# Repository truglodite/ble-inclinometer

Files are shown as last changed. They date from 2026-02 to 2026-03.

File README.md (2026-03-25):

# ble-inclinometer

### Measure pitch and throw angles on RC aircraft and helis, using the Xiao NRF52840 Sense.

## Features:
* Extremely Small and lightweight sensor form factor vs commercial inclinometers; won't spoil measurements on delicate/flexible surfaces with weak servos
* Very simple stand alone 1s battery only option works with Bluetooth LE using the "NRF Connect Mobile" app (iOS and Andriod)
* Optional OLED display and tare button, for convenient use without a phone (SSD1306)
* Works on surfaces at various angles (ailerons, vee tails, heli blades, etc)
* Sends accurate sub-degree roll and pitch angles ~1 per second, using a running average and floating point math with IMU optimizations
* Displays battery volts (the Xiao has a built in USB powered 1s lithium battery manager, with 50mA and 100mA charge options)
* Simplified PlatformIO flashing with open source libraries included
* LED status indicators (Blue = BLE connected, Green flash = Data updated, Red flash = Taring)
* 3D printable surface clip STL and OLED+button+battery enclosure files included

*Minimal assembly for BLE use, with just a 1s lipo connected to the XIAO*
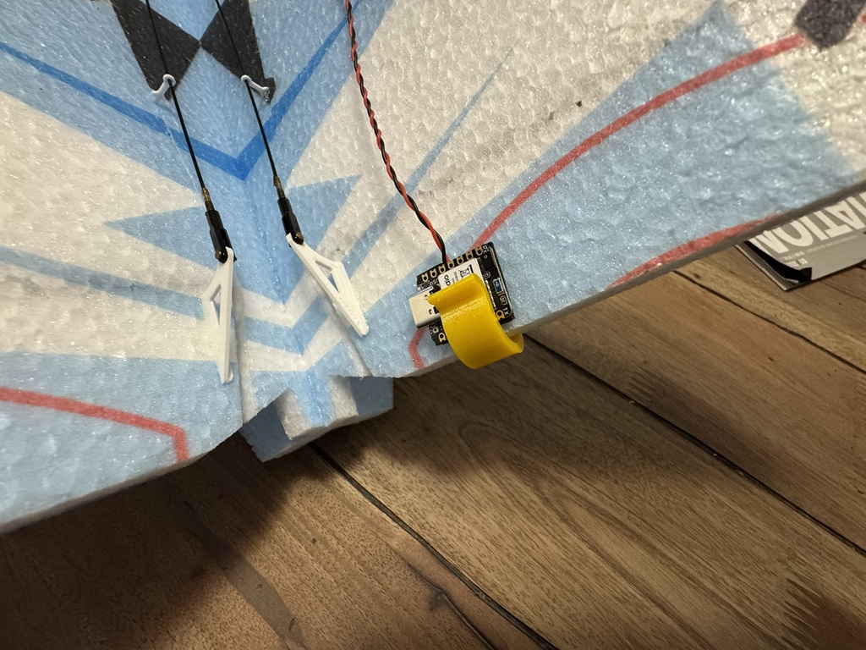
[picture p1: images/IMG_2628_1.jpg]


*Full featured assembly including OLED and tare button, using the included 3d printable files.*
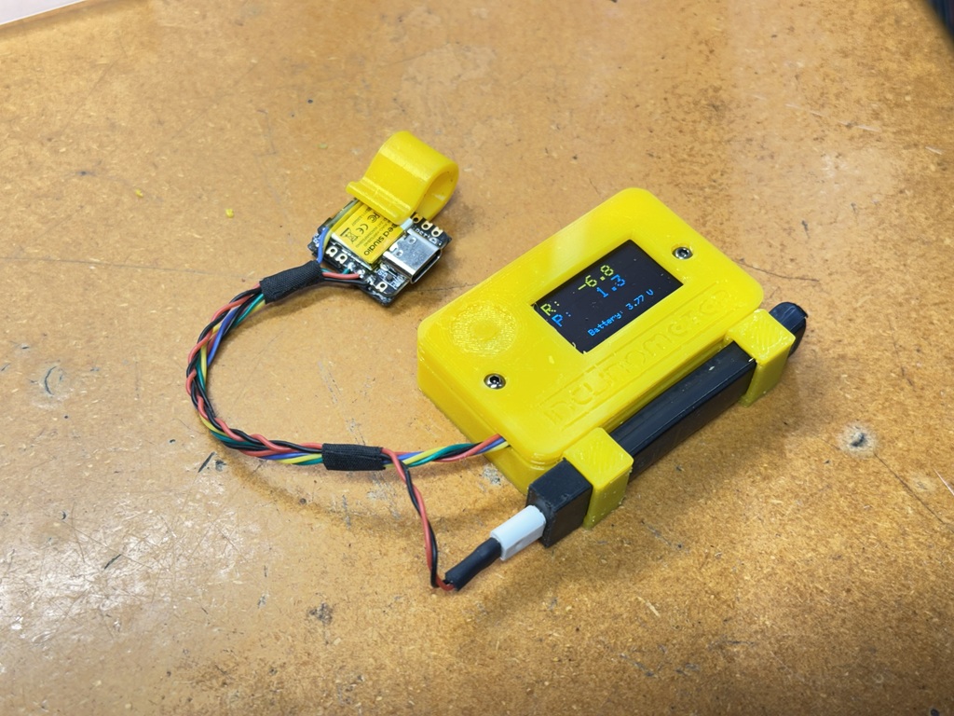
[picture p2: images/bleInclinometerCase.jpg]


## Hardware:
1@ Seeed Studio Xiao NRF52840 Sense board:

https://www.amazon.com/Seeed-Studio-XIAO-nRF52840-Pre-Soldered/dp/B09T94SZ8K/

1@ 1s lithium battery (pretty much any 1s will work):

https://www.amazon.com/flite-300mAh-3-7V-LiPo-Battery/dp/B01FTFZ1ZE/

1@ SSD1306 i2c OLED display (optional):

https://www.amazon.com/HiLetgo-Serial-128X64-Display-Color/dp/B06XRBTBTB/

1@ Momentary N.O. tactile button (optional):

https://www.amazon.com/DAOKI-100Pcs-6x6x5mm-Momentary-Tactile/dp/B07X8T9D2Q/
## Flashing:
#### Flash w/ PlatformIO (recommended):
This option might be easier, since the libraries are included in this repo. I won't go into details of how to use PlatformIO, but it is fairly simple. Download and install vscode, and install the platformIO extension in vscode. Download and unzip this repo to your "Projects" folder, and "Open Folder" in platformio home. Use the right arrow near the bottom to compile and flash.
#### Flash w/ Arduino IDE:
If you don't have the Arduino IDE and Seeed libraries installed on your PC and have a grasp on flashing an Arduino, you should start by reading the software section of this page:

  https://wiki.seeedstudio.com/XIAO_BLE/
  
Note this project will use the "Seeed nRF52 mbed-enabled Boards" since it needs the IMU. You will also have to install the Seeed gyro lib as shown on this page:

  https://wiki.seeedstudio.com/XIAO-BLE-Sense-IMU-Usage/
## Assembly:
Device Pin | Xiao Pin
------------ | ------------
battery +   | Bat+
battery -   | Bat-
OLED VCC    | 3v3
OLED GND    | GND
OLED SDA    | 4
OLED SCL    | 5
button 1a   | 10
button 1b   | gnd

The entire circuit uses very little current. So 30awg or even smaller wire should be adequate. Wire a 1s lithium battery to the BAT+/- pads on the back of the board. The battery can be anything from a rechargeable LR2032 coin cell up to a giant 5000mAh lipo. I recommend using a battery connector, as the battery will drain over time if left connected while not being used. I soldered some 30awg wire to a BT2.0 connector, and use one of my old/tired 1s300 tinywhoop lipos for power. If you are using an OLED and/or a tare button, wire them as shown in the table above.

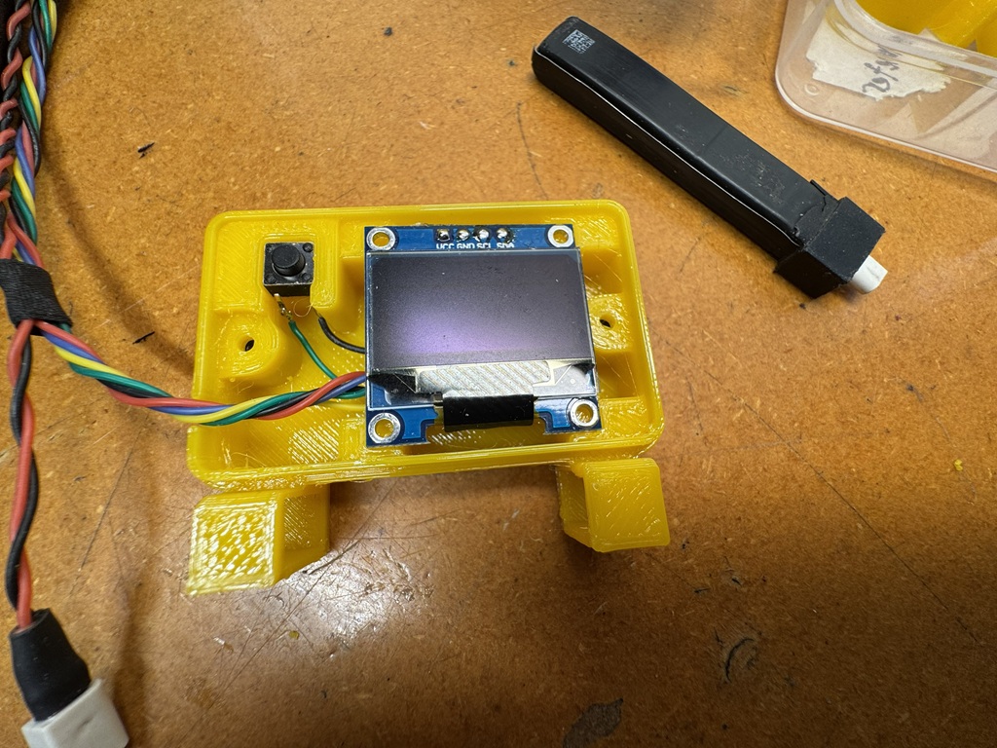
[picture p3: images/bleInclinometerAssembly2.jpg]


Twisted 30awg silicone wire harnesses will have very little effect on movement, even with very weak servos. Avoid using a lot of heatshrink on the harness, or anything else that might make it stiffer. Make the harness long enough so the battery (and OLED+button) can can be comfortably positioned away from the surface without any wire tension during measurments. 6" is usually enough for planes; heli pilots may want a longer harness. Avoid going much longer than ~12" if possible when using an OLED screen; very long wires may result in i2c errors.

It's a good idea to add some protection so the wires don't get damaged over time. I cut pieces of thick/tacky rubber tape (3m 2242) to make a tunnel for the battery wires. This way the board lies in plane with the surface without pinching or rocking on wires. The included clip files are best printed in TPU. They are very gentle on planes, and hold the board securely when 2242 tape is used on the board. Of course you can just use clothespins or whatever else if a 3d printer is not available.

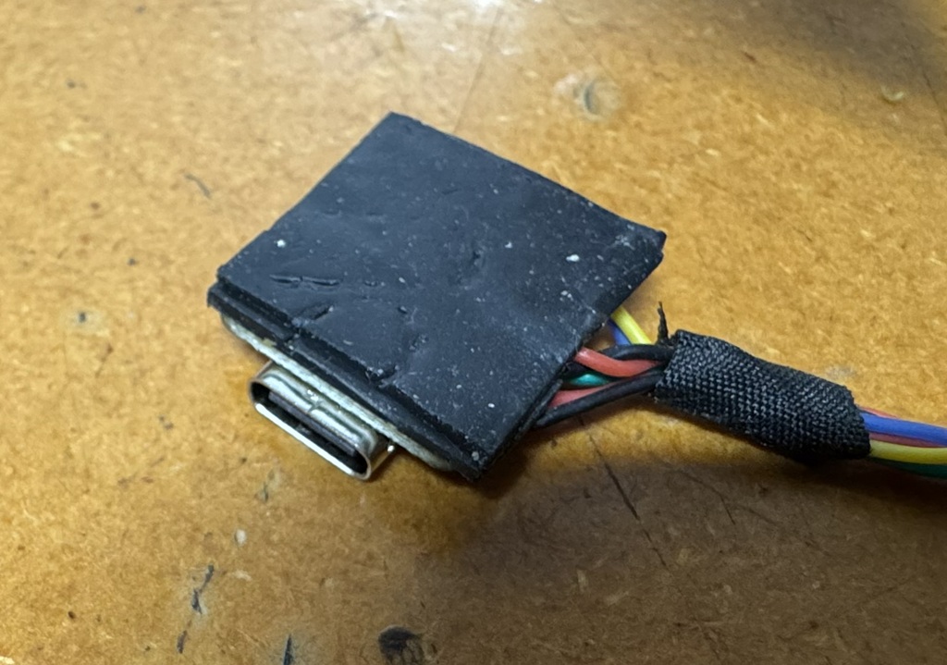
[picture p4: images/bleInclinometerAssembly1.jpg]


If you are using the 3d printable case, TPU is best for durability and to allow easy operation of the 'membrane' tare button. Supports are required for the membrane button and lipo holder areas (not in the text or screw holes). Run the wires through the hole, which has strain relief built in. The button and OLED set in the bottom of the case, and the top is secured with M2 bolts and nuts (the bolt length can vary from 6mm to 17mm; I used M2x7).

## General Use:
Clip the XIAO on the control surface to be measured and procede with measurements as needed. It is best to clip the sensor to your surface such that the roll axis (usb port) is aligned with the axis of rotation (aka "hinge line" or "feathering shaft"). When aligned perfectly, the pitch angle will not change with deflection, and the roll display will perfectly represent travel. Some small changes in pitch angle are fine. However if your measurement requires very high accuracy and you see larger changes in pitch while moving the surface (> +/-5degrees), you may want to try improving the alignment.

Take care the airframe does not move much while measuring (for example keep plane in a cradle so tailwheels/tillers are off the ground). Since only accelerometers are used, measuring yaw is not possible. Therefore you may have to tilt the airframe to measure surfaces that normally rotate about a vertical axis (ie rudders). It isn't necessary to have the surface completely horizontal; within 60 degrees of horizontal is usually good enough to get accurate measurements.

Use the Tare function (via button or BLE) to zero the angles at any position (ie sticks centered after subtrim). Use measurements to setup surface endpoints, control rates, etc.
#### Bluetooth Details:
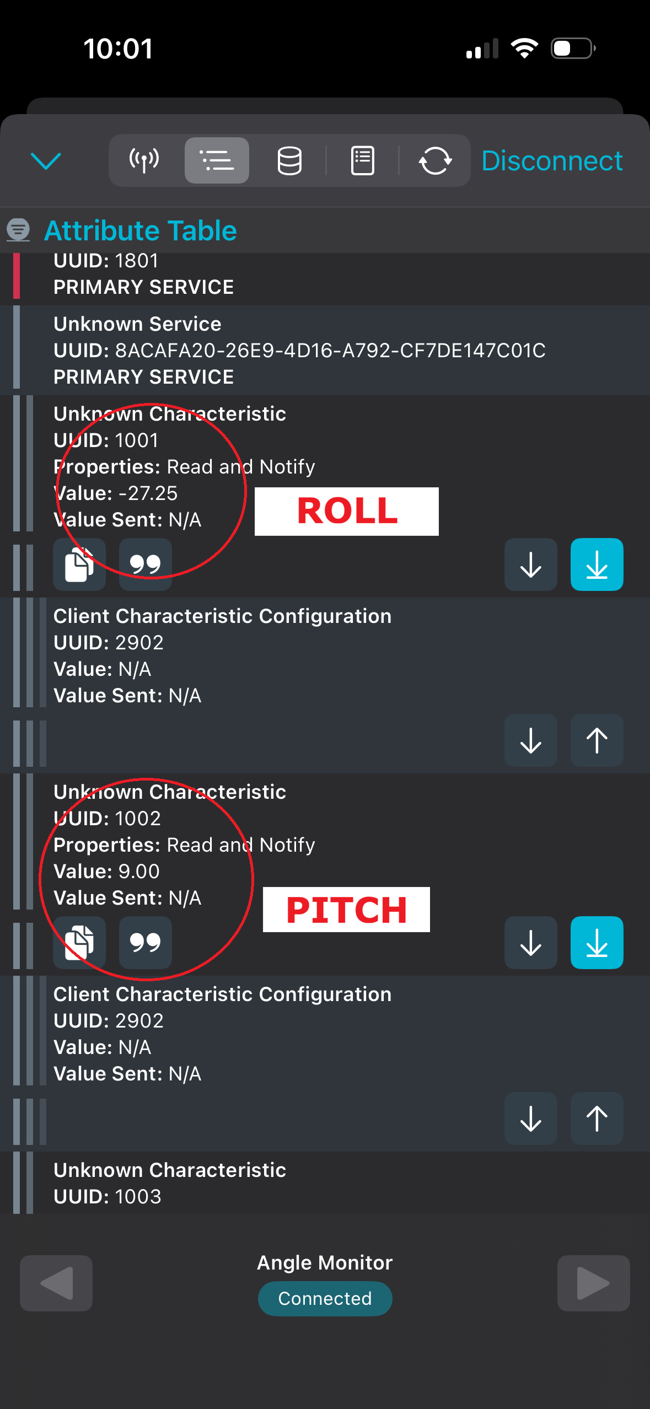
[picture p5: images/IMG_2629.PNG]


UUID | Name | Units
--- | -------- | ---
1001 | Roll axis | degrees
1002 | Pitch axis | degrees
1003 | Tare both axis | send "TRUE"
1004 | Battery Voltage | V

Install the "NRF Connect" app on your phone. When you power up your inclinometer, it will show up in the app as *"Angle Monitor"*. Connect to it, and the characteristics (sensors and controls) will appear in a list. Click the *"down-bar"* arrows on the sensor UUID's (1001, 1002, & 1003) to get continuously updated values. Click the *"quotes"* and select *"UTF-8"*. Now the angles and voltage should display correctly. Tare by clicking the "Up Arrow" on the tare UUID (1003), and send a Boolean "True" (or an UnsignedInt "1").

If you are use an OLED, bluetooth connection info will show on the screen. If you have not enabled "formatOledBig, the bluetooth info line will either show "BT: disconnected" if no phone is connected, or "BT: (MAC address of connected phone)". If you use "formatOledBig", bluetooth info and battery voltage will alternate on the bottom line every ~2.5seconds.

Proper descriptor names are included with all BLE characteristics. Unfortunately NRF Connect (and many similar apps) do not read or make use of them. If there's an app that does, actual sensor names are available in the transmissions.
## Notes:
* The roll is axis is oriented "going in to the USB"
* The pitch axis is oriented "across the width of the USB"
* Use the "chargeCurrent" compile option to select between 50mA and 100mA battery charging current (50mA default)
* "updateDelay" compile option to adjust refresh rate (1sec default, limited by the phone app)
* Compile using the mbed board definition: "Seeed NRF-52 mbed enabled boards\Xiao nRF52840 Sense (No Update)"
* Use the "oledFormatBig" compile option for a larger font. Best for monochrome SSD1306 displays (not so great with Y/B displays)
* Uploaded stl files in 3 sizes: 0mm, 3mm, and 6mm. Print a set with TPU to suit many different surface thicknesses... or just use a clothes pin.
## Project Roadmap:
* ...done?

I'm not a professional programmer, and this project is nothing special. Please use, modify, and/or share the code however you wish. ;)

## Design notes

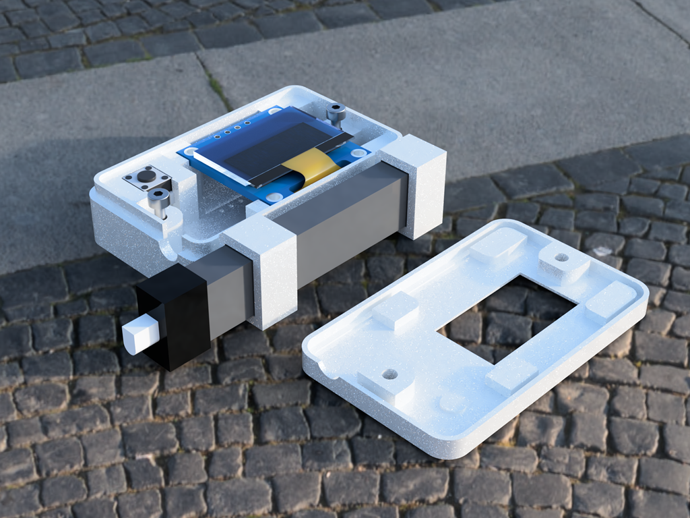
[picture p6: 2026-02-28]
images/bleInclinometerCase3.PNG

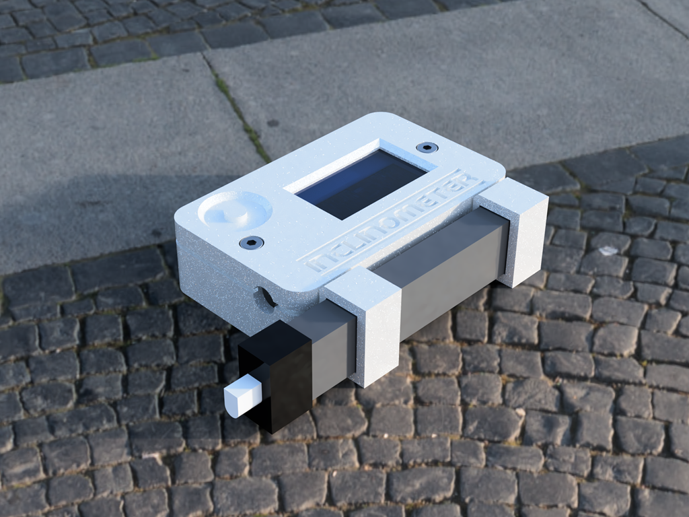
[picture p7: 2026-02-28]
images/bleInclinometerCase1.PNG

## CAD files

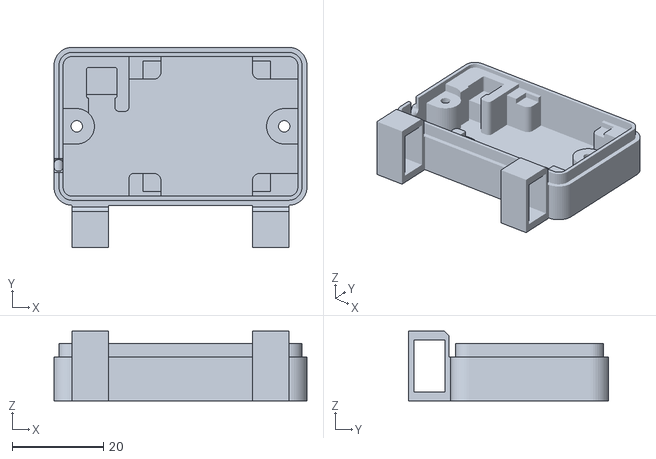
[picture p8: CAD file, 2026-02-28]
models/bleInclinometerCaseBottom.stl
55.6 x 44.0 x 15.3

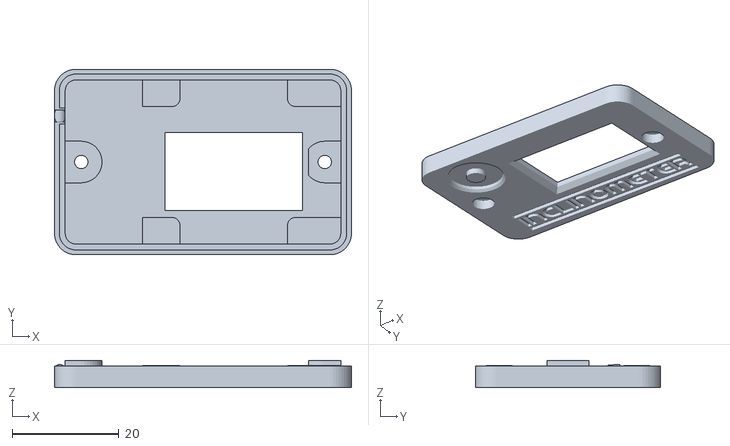
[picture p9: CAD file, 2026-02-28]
models/bleInclinometerCaseTop.stl
55.6 x 34.7 x 5.08

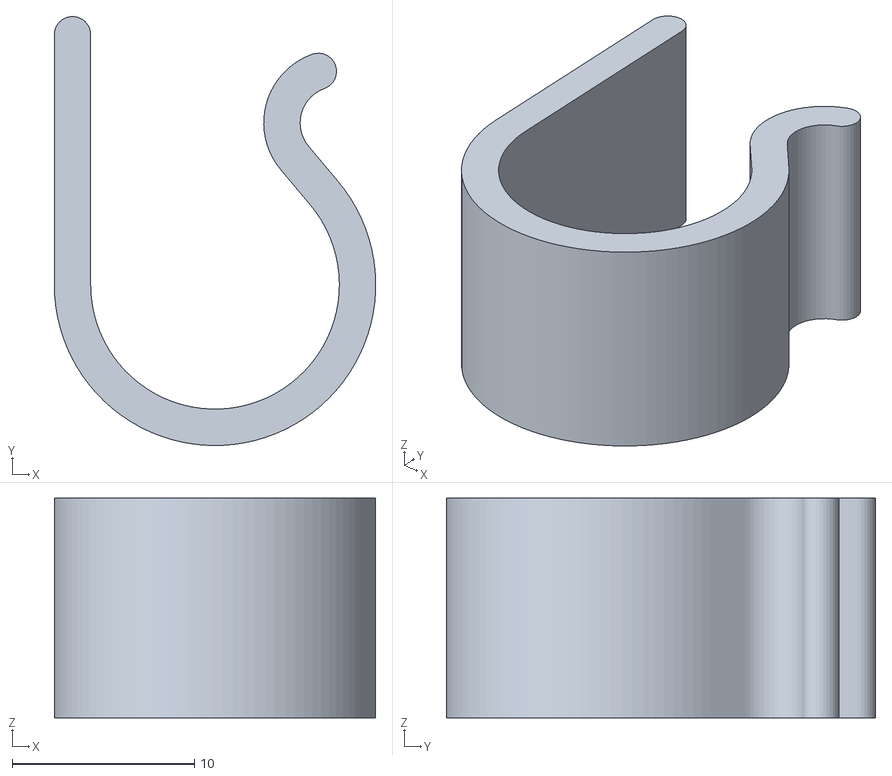
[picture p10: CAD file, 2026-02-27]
models/bleInclinometerClip6mm.stl
17.7 x 23.6 x 12.1

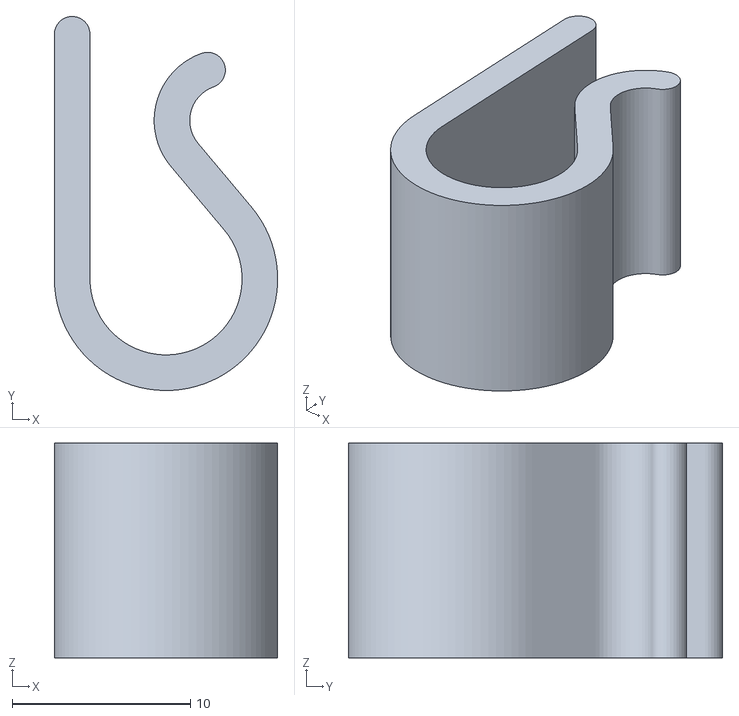
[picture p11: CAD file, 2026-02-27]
models/bleInclinometerClip0mm.stl
12.5 x 21.0 x 12.1

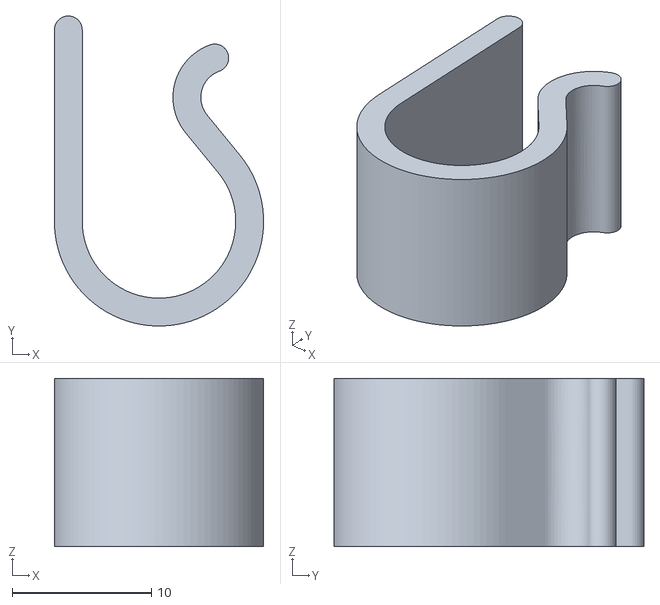
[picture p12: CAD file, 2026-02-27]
models/bleInclinometerClip3mm.stl
15.0 x 22.2 x 12.1

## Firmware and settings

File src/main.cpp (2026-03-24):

// ble-inclinometer
// written by: Truglodite 2/26/26
// The perfect tool for setting rc aircraft control throw, and other angle measurement needs.
// This code is written for the "Xiao NRF52840 Sense" board (use the "mbed" board definition).
// Standalone use with just a battery and a phone app (NRF Connect Mobile, for iOS and Android).
// Optional OLED display can be used for operation without a phone (SSD1306 i2c).
// Optional tare button can be connected for operation without a phone.

// Usage:
// Flash the board, power it on, and connect it to the app.
// Subscribe to the roll (1001) and pitch (1002) sensors ("down/line arrow" buttons).
// Configure the data as "UTF-8" ("quote" buttons).
// To zero both axis, send a true boolean (or 1) to the tare service (1003) (up arrow on sensor w/ long uuid), or push the tare button.
// If using a battery for power via the battery pads, subscribe to the battery service (1004) to read battery volts.
// Roll axis goes into the usb, pitch is across the usb.
// LEDs indicate status: Blue = BLE connected, Green flash = Data updated, Red flash = Taring

//  Wiring:
//  Device Pin | Xiao Pin
//  ------------ | ------------
//  battery +   | Bat+
//  battery -   | Bat-
//  OLED VCC    | 3v3
//  OLED GND    | GND
//  OLED SDA    | 4
//  OLED SCL    | 5
//  button 1a   | 10
//  button 1b   | gnd

// Arduino requires the seeed gyro lib (not the 'duino download): https://github.com/Seeed-Studio/Seeed_Arduino_LSM6DS3

#include <Arduino.h>
#include "ArduinoBLE.h"
#include "LSM6DS3.h"
#include "Wire.h"
#include <nrf52840.h>
#include <nrfx_saadc.h>
#include <AnalogIn.h>
#include <pinDefinitions.h>
#include <avr/dtostrf.h>
#include <Adafruit_SSD1306.h>

// User configuration
#define sampleCount 100 // # of samples between readings
#define tareLEDtime 2000   // msec wait while taring angles (longer than time required to collect sampleCount data points)
#define dataFlash 50   // msec to flash when data is sent
#define chargeCurrent LOW // Built in battery charger: HIGH = 50mA, LOW = 100mA
#define ledColorData LED_GREEN  // LED indicator colors, choose one each (LED_GREEN, LED_RED, LED_BLUE)
#define ledColorBLE LED_BLUE
#define ledColorTare LED_RED
#define tareButtonPin 11  // Pin connected to tare button (11 is IO, 10 is MOSI :P)
//#define oledFormatBig // uncomment for a larger degree display on the OLED (nice for single color screens, not so great with Y/B screens)
#define displayAlternatePeriod 2500 // msec to alternate between info when using oledFormatBig

// END User configuration

#define chargePin P0_13
#define batteryReadPin P0_14
#define batteryAnalogPin P0_31
LSM6DS3 myIMU(I2C_MODE, 0x6A);    //I2C device address 0x6A

// Characteristic UUID's
#define BLE_UUID_ANGLE_MONITOR_SERVICE "8acafa20-26e9-4d16-a792-cf7de147c01c"  // v4 random uuid
#define BLE_UUID_ROLL_DEGREES  "1001"
#define BLE_UUID_PITCH_DEGREES  "1002"
#define BLE_UUID_TARE_SWITCH  "1003"
#define BLE_UUID_BATTERY_VOLTS  "1004"
//#define BLE_UUID_BATTERY_VOLTS  "5726c19a-8a75-5d7a-845d-aadf6734d7e7"  // V5 uuid's
//#define BLE_UUID_ROLL_DEGREES  "a68e1ad6-8c88-56f4-b9d5-792af19cfb19"
//#define BLE_UUID_PITCH_DEGREES  "d9bc177b-1fbe-5724-867a-558e397f2401"
//#define BLE_UUID_TARE_SWITCH  "f7a73029-a679-5de1-8448-ba3d23450f75"

// Bluetooth® Low Energy Battery Service
BLEService angleMonitorService(BLE_UUID_ANGLE_MONITOR_SERVICE);

// Bluetooth® Low Energy Characteristics & Descriptors
BLEStringCharacteristic batteryVolts(BLE_UUID_BATTERY_VOLTS, BLERead | BLENotify, 20);
BLEStringCharacteristic rollDegrees(BLE_UUID_ROLL_DEGREES, BLERead | BLENotify, 20);
BLEStringCharacteristic pitchDegrees(BLE_UUID_PITCH_DEGREES, BLERead | BLENotify, 20);
BLEByteCharacteristic tareChar(BLE_UUID_TARE_SWITCH, BLERead | BLEWrite);

// BLE Descriptors (not read by NRF connect app unfortunately, but here in case some app does)
BLEDescriptor pitchDegreesDescriptor("2901", "Pitch Degrees");
BLEDescriptor rollDegreesDescriptor("2901", "Roll Degrees");
BLEDescriptor batteryVoltsDescriptor("2901", "Batt Volts");
BLEDescriptor tareCharDescriptor("2901", "Tare");

// SSD1306 OLED display parameters
#define SCREEN_WIDTH 128
#define SCREEN_HEIGHT 64
#define OLED_RESET    -1

// I²C pins used by the SSD1306
// Xiao nRF52840 Sense: pin 4 and pin 5
Adafruit_SSD1306 display(SCREEN_WIDTH, SCREEN_HEIGHT, &Wire, OLED_RESET);

float battery = 0.0;  // battery voltage
char batteryBuffer[20]; // printable byte array
float roll = 0;  // roll angle
char rollBuffer[20]; // printable byte array
float pitch = 0;  // pitch angle
char pitchBuffer[20]; // printable byte array
float rollRaw = 0.0;  // raw calculated roll
float pitchRaw = 0.0;  // raw calculated pitch
float accX = 0.0; // accelerator sums
float accY = 0.0;
float accZ = 0.0;
float tareRoll = 0.0;  // raw roll value when tared
float tarePitch = 0.0;  // raw pitch value when tared
long currentMillis = 0; // global timer
long previousData = 0;  // msec since data was sent
long previousTare = 0;  // msec timer for data led flash
long previousDisplay = 0;  // msec timer for data led flash
u_int8_t displayIndex = 0; // display index for alternating displays
bool dataLedFlag = 0;  // flag for data led flash
bool tareFlag = 0;  // flag for tare routine
bool tareLedFlag = 0; // flag for tare led timer
bool centralFlag = 0; // flag if BLE is connected
String centralAddress = "0"; // array to store MAC address of connected BLE device
u_int8_t samples = 0;  // sample count storage

#define SPLASH_HEIGHT   64
#define SPLAST_WIDTH    128

static const unsigned char splashScreen[] = { // Size 128x64 pixels
    0xff, 0xff, 0xff, 0xff, 0xff, 0xff, 0xff, 0xff, 0xff, 0xff, 0xff, 0xff, 0xff, 0xff, 0xff, 0xff,
    0xff, 0xff, 0xff, 0xff, 0xff, 0xff, 0xff, 0xff, 0xff, 0xff, 0xff, 0xff, 0xff, 0xff, 0xff, 0xff,
    0xff, 0xff, 0xff, 0xff, 0xff, 0xff, 0xff, 0xff, 0xff, 0xff, 0xff, 0xff, 0xff, 0xff, 0xff, 0xff,
    0xff, 0xff, 0xff, 0xff, 0xff, 0xff, 0xc0, 0x00, 0x00, 0x1f, 0xff, 0xff, 0xff, 0xff, 0xff, 0xff,
    0xff, 0xff, 0xff, 0xff, 0xff, 0xff, 0xc0, 0x00, 0x00, 0x1f, 0xff, 0xff, 0xff, 0xff, 0xff, 0xff,
    0xff, 0xff, 0xff, 0xff, 0xff, 0xff, 0xff, 0xff, 0xff, 0xff, 0xff, 0xff, 0xff, 0xff, 0xff, 0xff,
    0xff, 0xff, 0xff, 0xff, 0xff, 0xff, 0xff, 0xff, 0xff, 0xff, 0xff, 0xff, 0xff, 0xff, 0xff, 0xff,
    0xff, 0xff, 0xff, 0xff, 0xff, 0xff, 0xe0, 0x13, 0xf8, 0x1f, 0xff, 0xff, 0xff, 0xff, 0xff, 0xff,
    0xff, 0xff, 0xff, 0xff, 0xff, 0xff, 0xe7, 0x93, 0xf1, 0xff, 0xff, 0xff, 0xff, 0xff, 0xff, 0xff,
    0xff, 0xff, 0xff, 0xff, 0xff, 0xff, 0xe7, 0x93, 0xf3, 0xff, 0xff, 0xff, 0xff, 0xff, 0xff, 0xff,
    0xff, 0xff, 0xff, 0xff, 0xff, 0xff, 0xe4, 0x13, 0xf2, 0x1f, 0xff, 0xff, 0xff, 0xff, 0xff, 0xff,
    0xff, 0xff, 0xff, 0xff, 0xff, 0xff, 0xe4, 0x13, 0xf2, 0x3f, 0xff, 0xff, 0xff, 0xff, 0xff, 0xff,
    0xff, 0xff, 0xff, 0xff, 0xff, 0xff, 0xe7, 0x93, 0xf1, 0xff, 0xff, 0xff, 0xff, 0xff, 0xff, 0xff,
    0xff, 0xff, 0xff, 0xff, 0xff, 0xff, 0xe0, 0x10, 0x38, 0x1f, 0xff, 0xff, 0xff, 0xff, 0xff, 0xff,
    0xff, 0xff, 0xff, 0xff, 0xff, 0xff, 0xe0, 0x30, 0x1c, 0x1f, 0xff, 0xff, 0xff, 0xff, 0xff, 0xff,
    0xff, 0xff, 0xff, 0xff, 0xff, 0xff, 0xff, 0xff, 0xff, 0xff, 0xff, 0xff, 0xff, 0xff, 0xff, 0xff,
    0xff, 0xff, 0xff, 0xff, 0xff, 0xff, 0xff, 0xff, 0xff, 0xff, 0xff, 0xff, 0xff, 0xff, 0xff, 0xff,
    0xff, 0xff, 0xff, 0xff, 0xff, 0xff, 0xc0, 0x00, 0x00, 0x0f, 0xff, 0xff, 0xff, 0xff, 0xff, 0xff,
    0xff, 0xff, 0xff, 0xff, 0xff, 0xff, 0xe0, 0x00, 0x00, 0x1f, 0xff, 0xff, 0xff, 0xff, 0xff, 0xff,
    0xff, 0xff, 0xff, 0xff, 0xff, 0xff, 0xff, 0xff, 0xff, 0xff, 0xff, 0xff, 0xff, 0xff, 0xff, 0xff,
    0xff, 0xff, 0xff, 0xff, 0xff, 0xff, 0xff, 0xff, 0xff, 0xff, 0xff, 0xff, 0xff, 0xff, 0xff, 0xff,
    0xff, 0xfc, 0x00, 0x00, 0x00, 0x00, 0x00, 0x00, 0x00, 0x00, 0x00, 0x00, 0x00, 0x00, 0xff, 0xff,
    0xff, 0xfc, 0x00, 0x00, 0x00, 0x00, 0x00, 0x00, 0x00, 0x00, 0x00, 0x00, 0x00, 0x00, 0xff, 0xff,
    0xff, 0xff, 0xff, 0xff, 0xff, 0xff, 0xff, 0xff, 0xff, 0xff, 0xff, 0xff, 0xff, 0xff, 0xff, 0xff,
    0xff, 0xff, 0xff, 0xff, 0xff, 0xff, 0xff, 0xff, 0xff, 0xff, 0xff, 0xff, 0xff, 0xff, 0xff, 0xff,
    0xff, 0xfc, 0xe0, 0xf8, 0x27, 0xce, 0x0f, 0x03, 0xc0, 0x0e, 0x04, 0x03, 0x02, 0x01, 0xff, 0xff,
    0xff, 0xfc, 0xc4, 0x71, 0xe7, 0xcc, 0x46, 0x31, 0x98, 0xcc, 0x7f, 0x1e, 0x3e, 0x31, 0xff, 0xff,
    0xff, 0xfc, 0x9f, 0x27, 0xe7, 0xc9, 0xf2, 0x79, 0x98, 0xcc, 0xff, 0x9e, 0x7e, 0x78, 0xff, 0xff,
    0xff, 0xfc, 0x9f, 0x27, 0xe7, 0xc9, 0xf2, 0x79, 0xbd, 0xed, 0x8f, 0x9e, 0x42, 0x61, 0xff, 0xff,
    0xff, 0xfc, 0x9f, 0x27, 0xe7, 0xc9, 0xf2, 0x79, 0x99, 0xec, 0x8f, 0x9e, 0x46, 0x41, 0xff, 0xff,
    0xff, 0xfc, 0x9f, 0x23, 0xe7, 0xc9, 0xf2, 0x39, 0x99, 0xec, 0xff, 0x9e, 0x3e, 0x71, 0xff, 0xff,
    0xff, 0xfc, 0x9f, 0x30, 0x20, 0x49, 0xf3, 0x03, 0x18, 0xc6, 0x07, 0x9f, 0x02, 0x78, 0xff, 0xff,
    0xff, 0xfc, 0x9f, 0x38, 0x20, 0x49, 0xf3, 0x87, 0xbd, 0xef, 0x07, 0x9f, 0x82, 0x7c, 0xff, 0xff,
    0xff, 0xff, 0xff, 0xff, 0xff, 0xff, 0xff, 0xff, 0xff, 0xff, 0xff, 0xff, 0xff, 0xff, 0xff, 0xff,
    0xff, 0xff, 0xff, 0xff, 0xff, 0xff, 0xff, 0xff, 0xff, 0xff, 0xff, 0xff, 0xff, 0xff, 0xff, 0xff,
    0xff, 0xfc, 0x00, 0x00, 0x00, 0x00, 0x00, 0x00, 0x00, 0x00, 0x00, 0x00, 0x00, 0x00, 0xff, 0xff,
    0xff, 0xfc, 0x00, 0x00, 0x00, 0x00, 0x00, 0x00, 0x00, 0x00, 0x00, 0x00, 0x00, 0x00, 0xff, 0xff,
    0xff, 0xff, 0xff, 0xff, 0xff, 0xff, 0xff, 0xff, 0xff, 0xff, 0xff, 0xff, 0xff, 0xff, 0xff, 0xff,
    0xff, 0xff, 0xff, 0xff, 0xff, 0xff, 0xff, 0xff, 0xff, 0xff, 0xff, 0xff, 0xff, 0xff, 0xff, 0xff,
    0xff, 0xff, 0xff, 0xff, 0xff, 0xff, 0xff, 0xff, 0xff, 0xff, 0xff, 0xff, 0xff, 0xff, 0xff, 0xff,
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
};

void readData()  {
  // Reads samples from the IMU and analog sensor, calculates the voltage and angles, and adds values to averaging sums
  int batteryADC = analogRead(batteryAnalogPin); // read battery adc
  battery += float(batteryADC); // calc actual battery volts w/ 3v3 reg and 10bit adc

  // Read angle between X and Z accelerometer axis
  accX += myIMU.readFloatAccelX();
  accY += myIMU.readFloatAccelY();
  accZ += myIMU.readFloatAccelZ();
}

void updateDataBuffers() {
  // Prints and updates data buffers
  // Calculate averaged and tared angles
  accX = accX / samples;
  accY = accY / samples;
  accZ = accZ / samples;
  rollRaw = atan2(accY, accZ) * 57.2958;
  pitchRaw = atan2(-accX, sqrt(accY * accY + accZ * accZ)) * 57.2958;
  roll = ( rollRaw ) - tareRoll;
  pitch = ( pitchRaw ) - tarePitch;
  // Calculate averaged battery voltage
  battery = battery / samples;
  battery = (battery * 3.3) / 1024 * 1510.0 / 510.0; // calc actual battery volts w/ 3v3 reg and 10bit adc

  // Stringify float angles to 1 decimal place
  dtostrf(roll, 5, 1, rollBuffer);
  dtostrf(pitch, 5, 1, pitchBuffer);
  // Stringify float voltage to 2 decimal places
  dtostrf(battery, 4, 2, batteryBuffer);

  // Print debug
  Serial.print("Roll/Pitch/Battery: ");
  Serial.print(rollBuffer);
  Serial.print(", ");
  Serial.print(pitchBuffer);
  Serial.print(", ");
  Serial.println(batteryBuffer);

  // rezero values
  samples = 0.0;
  accX = 0.0;
  accY = 0.0;
  accZ = 0.0;
  battery = 0.0;
}

void sendBLE() {
  // Sends data buffers to BLE
  rollDegrees.writeValue(rollBuffer);
  pitchDegrees.writeValue(pitchBuffer);
  batteryVolts.writeValue(batteryBuffer);
}

void sendOLED() {
  // Update the OLED
  display.clearDisplay();
  #ifdef oledFormatBig
    display.setTextSize(1);
    display.setTextColor(SSD1306_WHITE);
    display.setCursor(0, 0);
    display.print("R:");
    display.setTextSize(3);
    // right justify values
    // strf() takes care of most of the work since values range +-180.0
    if(roll > -100) { // add a space only if we have a value > -100
      display.print(" ");
    }
    display.println(rollBuffer);
    display.setTextSize(1);
    display.print("P:");
    display.setTextSize(3);
    if(pitch > -100) { // add a space only if we have a value > -100
      display.print(" ");
    }
    display.println(pitchBuffer);
    display.setTextSize(1);
    display.setCursor(0, 52);
    // update alternating display index when enough time has passed
    if ( currentMillis - previousDisplay > displayAlternatePeriod) {
      previousDisplay = currentMillis;
      if (displayIndex == 0)  {
        displayIndex = 1;
      }
      else {
        displayIndex = 0;
      }
    }
    // show alternating display based on the current index
    if (displayIndex == 0)
    {
      display.print("Battery:      ");
      display.print(batteryBuffer);
      display.println(" V");
    }
    else {
      display.print("BT: ");
      if (centralFlag) {   // show BLE connections
        display.println(centralAddress);
      }
      else {
        display.println("    disconnected");
      }
    }
  #endif
  #ifndef oledFormatBig
    display.setTextSize(2);
    display.setTextColor(SSD1306_WHITE);
    display.setCursor(0, 0);
    display.print("R: ");
    // right justify values
    // strf() takes care of most of the work since values range +-180.0
    if(roll > -100) { // add a space only if we have a value > -100
      display.print(" ");
    }
    display.print(rollBuffer);
    display.println((char)247); // degree symbol
    display.print("P: ");
    if(pitch > -100) { // add a space only if we have a value > -100
      display.print(" ");
    }
    display.print(pitchBuffer);
    display.println((char)247);
    
    display.setCursor(0, 38);
    display.setTextSize(1);
    display.print("BT: ");
    if (centralFlag) {   // show BLE connections
      display.println(centralAddress);
    }
    else {
      display.println("    disconnected");
    }
    display.setCursor(0, 52);
    display.print("Battery:      ");
    display.print(batteryBuffer);
    display.println(" V");
  #endif
  display.display();
}

void tareAxis() {
  // Sets axis zeros at the current position
  tareRoll = rollRaw;
  tarePitch = pitchRaw;
}

void setup()
{
  Serial.begin(115200);    // initialize serial communication
  delay(1000);    // give time for serial to startup

  pinMode(tareButtonPin, INPUT_PULLUP); // init tare button

  pinMode(LED_RED, OUTPUT); // initialize the built-in LEDs
  pinMode(LED_BLUE, OUTPUT);
  pinMode(LED_GREEN, OUTPUT);

  pinMode (chargePin, OUTPUT);  // init charge current setting pin
  pinMode (batteryReadPin, OUTPUT);  // init charge current setting pin

  Serial.println("BLE Inclinometer");
  Serial.println("by: Truglodite");
  // prepare I²C for the OLED
  Wire.begin();

  // Initialize SSD1306 OLED
  if(!display.begin(SSD1306_SWITCHCAPVCC, 0x3C)) { // 0x3C is common I2C address
    Serial.println("OLED failed!");
  } else {
    Serial.println("OLED - OK");
  }

  //Display Splashscreen
  display.clearDisplay();
  display.drawBitmap( 0, 0, splashScreen, SPLAST_WIDTH, SPLASH_HEIGHT, WHITE);
  display.display();
  delay(3000);

// …rest of setup()
  // begin initialization
  if (!BLE.begin()) 
  {
    Serial.println("BLE failed!");
  }
  else  {
    Serial.println("BLE - OK");
  }

  if (myIMU.begin() != 0) {
      Serial.println("IMU error!");
  } else {
      Serial.println("IMU - OK");
  }

  // Set advertised local name and service
  BLE.setDeviceName( "Angle Monitor" );
  BLE.setLocalName( "Angle Monitor" );
  BLE.setAdvertisedService( angleMonitorService );

  // Add Characteristic descriptors
  batteryVolts.addDescriptor(batteryVoltsDescriptor);
  rollDegrees.addDescriptor(rollDegreesDescriptor);
  pitchDegrees.addDescriptor(pitchDegreesDescriptor);
  tareChar.addDescriptor(tareCharDescriptor);

  // Add BLE characteristics
  angleMonitorService.addCharacteristic( batteryVolts );
  angleMonitorService.addCharacteristic( rollDegrees );
  angleMonitorService.addCharacteristic( pitchDegrees );
  angleMonitorService.addCharacteristic( tareChar );

  // Add Service
  BLE.addService( angleMonitorService );

  // Write initial values
  dtostrf(battery, 4, 2, batteryBuffer);
  batteryVolts.writeValue(batteryBuffer);
  dtostrf(roll, 5, 2, rollBuffer);
  rollDegrees.writeValue(rollBuffer);
  dtostrf(pitch, 5, 2, pitchBuffer);
  pitchDegrees.writeValue(pitchBuffer);
  tareChar.writeValue(0);

  // start advertising
  BLE.advertise();

  // Configure IMU for slow-precise angle measurement
  myIMU.settings.gyroEnabled = 0;  //Can be 0 or 1
  myIMU.settings.accelEnabled = 1;
  myIMU.settings.accelRange = 2;      //Max G force readable.  Can be: 2, 4, 8, 16
  myIMU.settings.accelSampleRate = 208;  //Hz.  Can be: 13, 26, 52, 104, 208, 416, 833, 1666, 3332, 6664, 13330
  myIMU.settings.accelBandWidth = 50;  //Hz.  Can be: 50, 100, 200, 400;

  digitalWrite(ledColorBLE, HIGH);  // Ensure LEDs are off before looping
  digitalWrite(ledColorData, HIGH);
  digitalWrite(ledColorTare, HIGH);

  Serial.println("Bluetooth® waiting for connections to 'Angle Monitor'");
}

void loop()
{
  digitalWrite(chargePin, chargeCurrent); // configure usb charger
  digitalWrite(batteryReadPin, LOW);  // configure battery measurement
  
  currentMillis = millis();

  BLEDevice central = BLE.central();

  // Check BLE central if not connected
  if (!central) {
    if(centralFlag)  {
      Serial.print("Disconnected from central: ");
      Serial.println(central.address());
      digitalWrite(ledColorBLE, HIGH);  // Turn off led while not connected
      centralFlag = 0;
    }
  }
  // Central is connected
  else  {
    if (!centralFlag)  {
      digitalWrite(ledColorBLE, LOW); // Turn on led while connected
      centralAddress = central.address();
      Serial.print("Connected to central: ");
      Serial.println(centralAddress);
      centralFlag = 1;
    }
  }

  // count more samples if needed
  if (samples < sampleCount)  {
    readData();
    samples++;
  }
  // enough samples, send data
  else  {
    previousData = currentMillis;
    updateDataBuffers();
    if (central.connected())  {
      sendBLE();
    }
    sendOLED();
    digitalWrite(ledColorData, LOW); // turn on data led flash
    dataLedFlag = 1;
  }
  // data led is on, and time to turn it off
  if (dataLedFlag && currentMillis - previousData >= dataFlash)  {
    digitalWrite(ledColorData, HIGH);
    dataLedFlag = 0;
  }

  // Handle tare button, no debounce needed since taring takes a while
  if (!digitalRead(tareButtonPin) && !tareFlag) {
    // Button is pressed and tare hasn't started
    previousTare = currentMillis; //start led timer
    digitalWrite(ledColorTare, LOW); // turn on tare led flash
    tareFlag = 1;
    tareLedFlag = 1;
    Serial.println("Tare axis via button");
  }

  // Tare recieved, turn on LED and set tare flag
  if (tareChar.written() && !tareFlag) {
    if (tareChar.value()) {    // received a HIGH value
      previousTare = currentMillis; //start led timer
      digitalWrite(ledColorTare, LOW); // turn on tare led flash
      tareFlag = 1;
      tareLedFlag = 1;
      Serial.println("Tare axis via BLE");
    }
  }
  // We have a tare flag, and enough samples to tare
  if (tareFlag && samples >= sampleCount) {
    tareAxis();
    tareFlag = 0;
  }
  // tare led is on, and time to turn it off
  if (tareLedFlag && currentMillis - previousTare >= tareLEDtime)  {
    digitalWrite(ledColorTare, HIGH);
    tareLedFlag = 0;
  }

}

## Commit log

2026-02-28 Fix readme and add spaces to OLED angles.
    [main.cpp]
2026-02-28 Add enclosure files and images.
    [bleInclinometerCaseBottom.stl, bleInclinometerCaseTop.stl]
2026-02-28 Shrink enclosure images, move image in readme.
2026-02-28 Update enclosure.
    [bleInclinometerCaseBottom.stl, bleInclinometerCaseTop.stl]
2026-02-28 Add assemly and case images
2026-02-28 Enhance README with images and usage instructions
    Added images and improved instructions for wire harness and general use.
2026-02-28 Update README with assembly details and remove duplicates
    Removed duplicate images and added assembly descriptions for BLE use and full-featured assembly.
2026-02-28 Update README with wiring and protection tips
    Added recommendations for wire harness length and protection.
2026-02-28 Update README with TPU case usage and alignment tips
    Added recommendations for using TPU in the 3D printable case and provided details on assembly and alignment for accurate measurements.
2026-03-24 refactor main, add info on case to readme.
